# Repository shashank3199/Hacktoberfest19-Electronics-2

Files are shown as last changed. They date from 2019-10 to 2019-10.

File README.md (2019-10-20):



# Electronics-2

## Introduction
This repository contains the board design for Manual Bot Controller Shield for Arduino Mega 2560.

## Layout

### Board File -

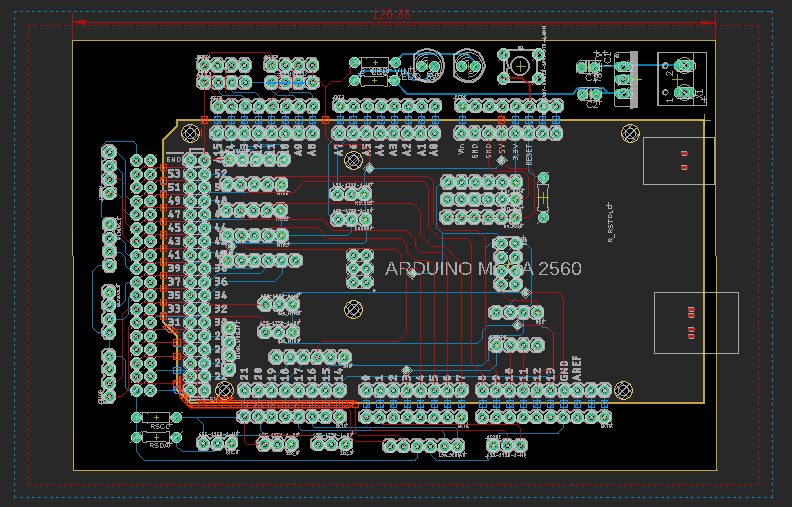
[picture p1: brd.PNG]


### Schematic File -

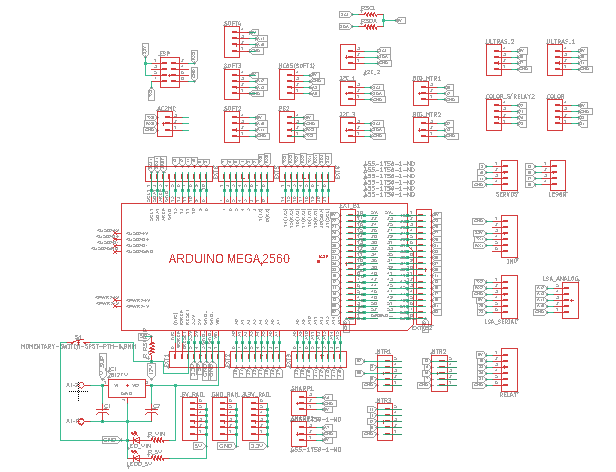
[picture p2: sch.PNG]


## Files in the Repository
The files in the repository are :

#### ManualBot_Shield.brd
This is the Board file and contains the Blueprint of the Shield Layout (Prototype).

#### ManualBot_Shield.sch
This is the Schematic file and contains the actual circuitary behind the Shield.

#### README.md
The Description file containing details about the repository. The file that you looking at right now.




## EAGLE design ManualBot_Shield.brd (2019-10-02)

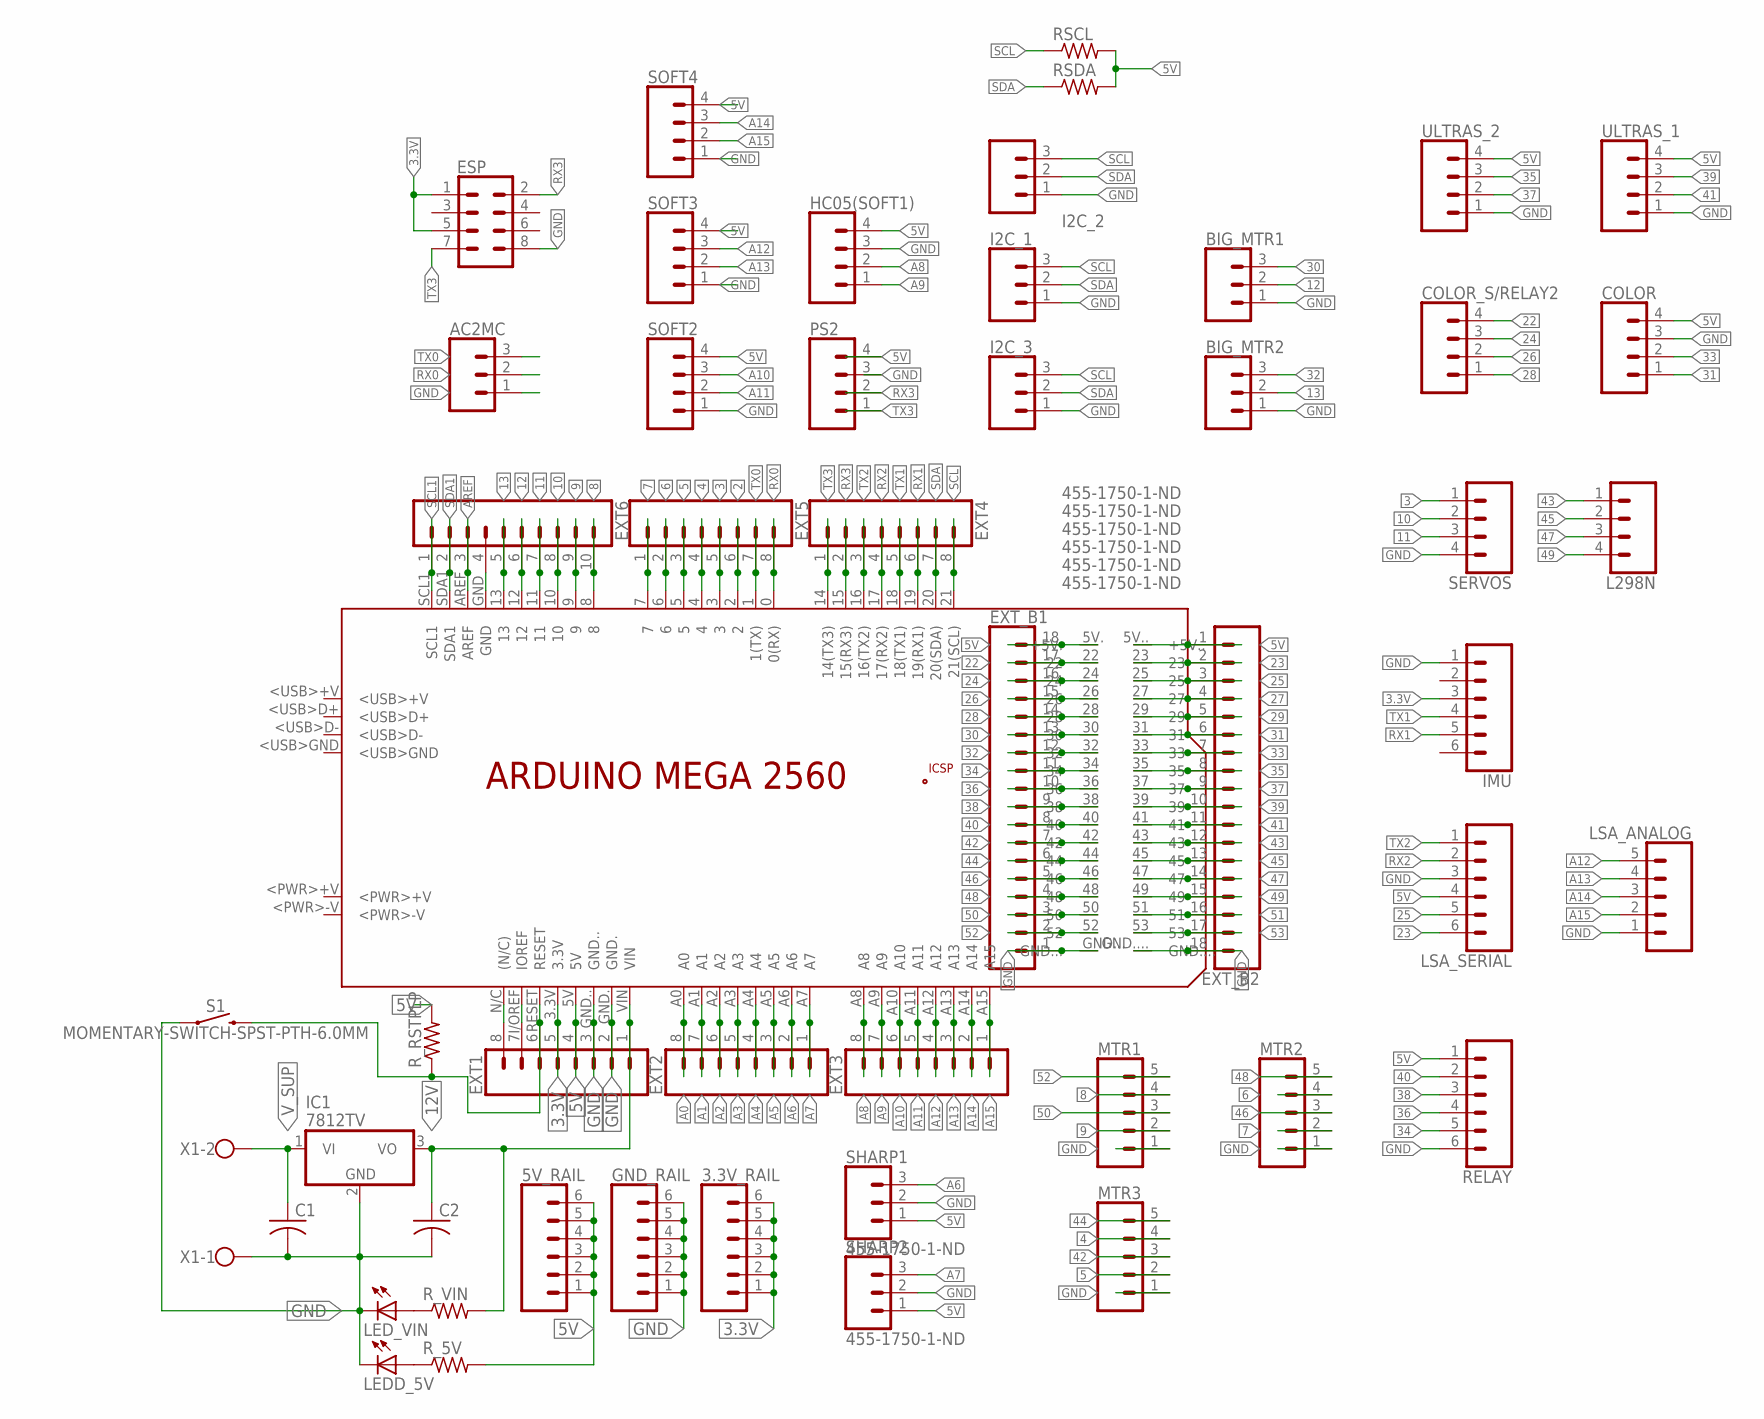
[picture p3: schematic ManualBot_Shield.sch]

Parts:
3.3V_RAIL, 5V_RAIL: CONN_06SILK_FEMALE_PTH; 1X06
AC2MC: 455-1750-1-ND; 1X03
BIG_MTR1, BIG_MTR2: 455-1750-1-ND; 1X03
C1, C2: C-US025-024X044; C025-024X044
COLOR: CONN_04; 1X04
COLOR_S/RELAY2: CONN_04; 1X04
ESP: CONN_04X2; 2X4
EXT1, EXT2, EXT3, EXT4, EXT5: CONN_08"; 1X08
EXT6: CONN_10"; 1X10
EXT_B1, EXT_B2: CONN_18; 1X18_NO_SILK
GND_RAIL: CONN_06SILK_FEMALE_PTH; 1X06
HC05(SOFT1): CONN_04; 1X04
I2C_1, I2C_2, I2C_3: 455-1750-1-ND; 1X03
IC1: 7812TV; TO220V
IMU: CONN_06SILK_FEMALE_PTH; 1X06
L298N: CONN_04; 1X04
LEDD_5V: LED5MM
LED_VIN: LED5MM
LSA_ANALOG: CONN_05; 1X05
LSA_SERIAL: CONN_06SILK_FEMALE_PTH; 1X06
MTR1, MTR2, MTR3: CONN_05; 1X05
PCB1: ARDUINO_MEGA2560
PS2: CONN_04; 1X04
RELAY: CONN_06SILK_FEMALE_PTH; 1X06
RSCL: R-US_0204/7; 0204/7
RSDA: R-US_0204/7; 0204/7
R_5V: R-US_0204/7; 0204/7
R_RSTPLP: R-US_0204/7; 0204/7
R_VIN: R-US_0204/7; 0204/7
S1: MOMENTARY-SWITCH-SPST-PTH-6.0MM; TACTILE_SWITCH_PTH_6.0MM
SERVOS: CONN_04; 1X04
SHARP1, SHARP2: 455-1750-1-ND; 1X03
SOFT2, SOFT3, SOFT4: CONN_04; 1X04
ULTRAS_1, ULTRAS_2: CONN_04; 1X04
X1: W237-102

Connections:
2: EXT5.6, PCB1.2
3: EXT5.5, PCB1.3, SERVOS.1
3.3V: 3.3V_RAIL.1, 3.3V_RAIL.2, 3.3V_RAIL.3, 3.3V_RAIL.4, 3.3V_RAIL.5, 3.3V_RAIL.6, ESP.1, ESP.5, EXT1.5, IMU.3, PCB1.3.3V
4: EXT5.4, MTR3.4, PCB1.4
5: EXT5.3, MTR3.2, PCB1.5
5V: 5V_RAIL.1, 5V_RAIL.2, 5V_RAIL.3, 5V_RAIL.4, 5V_RAIL.5, 5V_RAIL.6, COLOR.4, EXT1.4, EXT_B1.18, EXT_B2.1, HC05(SOFT1).4, LSA_SERIAL.4, PCB1.5V, PCB1.5V. (+5V.), PCB1.5V.. (+5V..), PS2.4, RELAY.1, RSCL.2, RSDA.2, R_5V.2, R_RSTPLP.2, SHARP1.1, SHARP2.1, SOFT2.4, SOFT3.4, SOFT4.4, ULTRAS_1.4, ULTRAS_2.4
6: EXT5.2, MTR2.4, PCB1.6
7: EXT5.1, MTR2.2, PCB1.7
8: EXT6.10, MTR1.4, PCB1.8
9: EXT6.9, MTR1.2, PCB1.9
10: EXT6.8, PCB1.10, SERVOS.2
11: EXT6.7, PCB1.11, SERVOS.3
12: BIG_MTR1.2, EXT6.6, PCB1.12
12V: C2.1, EXT1.1, IC1.3 (VO), PCB1.VIN, R_VIN.2
13: BIG_MTR2.2, EXT6.5, PCB1.13
22: COLOR_S/RELAY2.4, EXT_B1.17, PCB1.22
23: EXT_B2.2, LSA_SERIAL.6, PCB1.23
24: COLOR_S/RELAY2.3, EXT_B1.16, PCB1.24
25: EXT_B2.3, LSA_SERIAL.5, PCB1.25
26: COLOR_S/RELAY2.2, EXT_B1.15, PCB1.26
27: EXT_B2.4, PCB1.27
28: COLOR_S/RELAY2.1, EXT_B1.14, PCB1.28
29: EXT_B2.5, PCB1.29
30: BIG_MTR1.3, EXT_B1.13, PCB1.30
31: COLOR.1, EXT_B2.6, PCB1.31
32: BIG_MTR2.3, EXT_B1.12, PCB1.32
33: COLOR.2, EXT_B2.7, PCB1.33
34: EXT_B1.11, PCB1.34, RELAY.5
35: EXT_B2.8, PCB1.35, ULTRAS_2.3
36: EXT_B1.10, PCB1.36, RELAY.4
37: EXT_B2.9, PCB1.37, ULTRAS_2.2
38: EXT_B1.9, PCB1.38, RELAY.3
39: EXT_B2.10, PCB1.39, ULTRAS_1.3
40: EXT_B1.8, PCB1.40, RELAY.2
41: EXT_B2.11, PCB1.41, ULTRAS_1.2
42: EXT_B1.7, MTR3.3, PCB1.42
43: EXT_B2.12, L298N.1, PCB1.43
44: EXT_B1.6, MTR3.5, PCB1.44
45: EXT_B2.13, L298N.2, PCB1.45
46: EXT_B1.5, MTR2.3, PCB1.46
47: EXT_B2.14, L298N.3, PCB1.47
48: EXT_B1.4, MTR2.5, PCB1.48
49: EXT_B2.15, L298N.4, PCB1.49
50: EXT_B1.3, MTR1.3, PCB1.50
51: EXT_B2.16, PCB1.51
52: EXT_B1.2, MTR1.5, PCB1.52
53: EXT_B2.17, PCB1.53
A0: EXT2.8, PCB1.A0
A1: EXT2.7, PCB1.A1
A2: EXT2.6, PCB1.A2
A3: EXT2.5, PCB1.A3
A4: EXT2.4, PCB1.A4
A5: EXT2.3, PCB1.A5
A6: EXT2.2, PCB1.A6, SHARP1.3
A7: EXT2.1, PCB1.A7, SHARP2.3
A8: EXT3.8, HC05(SOFT1).2, PCB1.A8
A9: EXT3.7, HC05(SOFT1).1, PCB1.A9
A10: EXT3.6, PCB1.A10, SOFT2.3
A11: EXT3.5, PCB1.A11, SOFT2.2
A12: EXT3.4, LSA_ANALOG.5, PCB1.A12, SOFT3.3
A13: EXT3.3, LSA_ANALOG.4, PCB1.A13, SOFT3.2
A14: EXT3.2, LSA_ANALOG.3, PCB1.A14, SOFT4.3
A15: EXT3.1, LSA_ANALOG.2, PCB1.A15, SOFT4.2
AREF: EXT6.3, PCB1.AREF
GND: AC2MC.1, BIG_MTR1.1, BIG_MTR2.1, C1.2, C2.2, COLOR.3, ESP.8, EXT1.2, EXT1.3, EXT6.4, EXT_B1.1, EXT_B2.18, GND_RAIL.1, GND_RAIL.2, GND_RAIL.3, GND_RAIL.4, GND_RAIL.5, GND_RAIL.6, HC05(SOFT1).3, I2C_1.1, I2C_2.1, I2C_3.1, IC1.2 (GND), IMU.1, LEDD_5V.K (C), LED_VIN.K (C), LSA_ANALOG.1, LSA_SERIAL.3, MTR1.1, MTR2.1, MTR3.1, PCB1.GND, PCB1.GND., PCB1.GND.., PCB1.GND..., PCB1.GND...., PS2.3, RELAY.6, S1.1, SERVOS.4, SHARP1.2, SHARP2.2, SOFT2.1, SOFT3.1, SOFT4.1, ULTRAS_1.1, ULTRAS_2.1, X1.1
unnamed: LED_VIN.A, R_VIN.1
unnamed: LEDD_5V.A, R_5V.1
unnamed: EXT1.6, PCB1.RESET, R_RSTPLP.1, S1.3 (2)
unnamed: EXT1.7, PCB1.I/OREF (IOREF)
unnamed: EXT1.8, PCB1.N/C ((N/C))
RX0: AC2MC.2, EXT5.8, PCB1.0 (0(RX))
RX1: EXT4.6, IMU.5, PCB1.19 (19(RX1))
RX2: EXT4.4, LSA_SERIAL.2, PCB1.17 (17(RX2))
RX3: ESP.2, EXT4.2, PCB1.15 (15(RX3)), PS2.2
SCL: EXT4.8, I2C_1.3, I2C_2.3, I2C_3.3, PCB1.21 (21(SCL)), RSCL.1
SCL1: EXT6.1, PCB1.SCL1
SDA: EXT4.7, I2C_1.2, I2C_2.2, I2C_3.2, PCB1.20 (20(SDA)), RSDA.1
SDA1: EXT6.2, PCB1.SDA1
TX0: AC2MC.3, EXT5.7, PCB1.1 (1(TX))
TX1: EXT4.5, IMU.4, PCB1.18 (18(TX1))
TX2: EXT4.3, LSA_SERIAL.1, PCB1.16 (16(TX2))
TX3: ESP.7, EXT4.1, PCB1.14 (14(TX3)), PS2.1
V_SUP: C1.1, IC1.1 (VI), X1.2

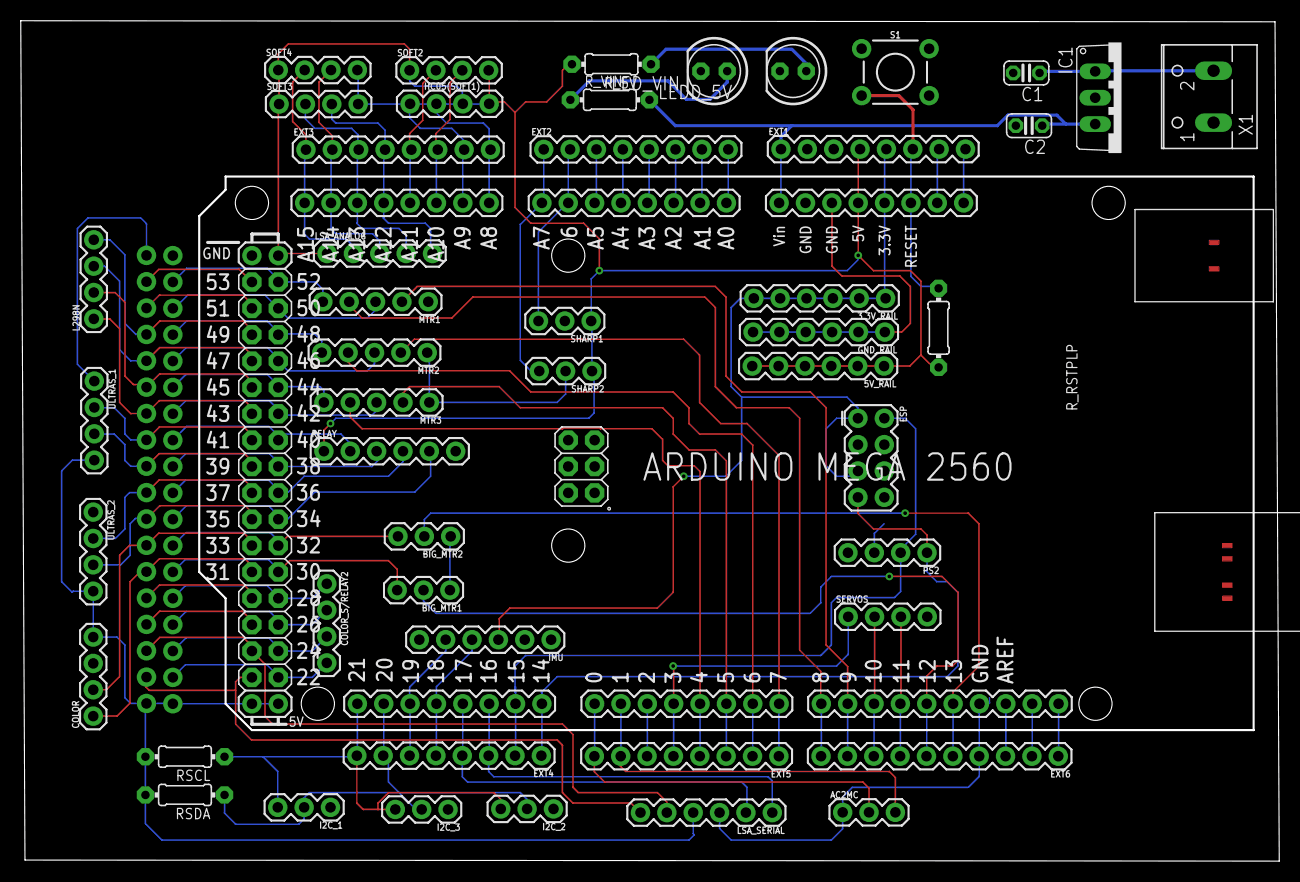
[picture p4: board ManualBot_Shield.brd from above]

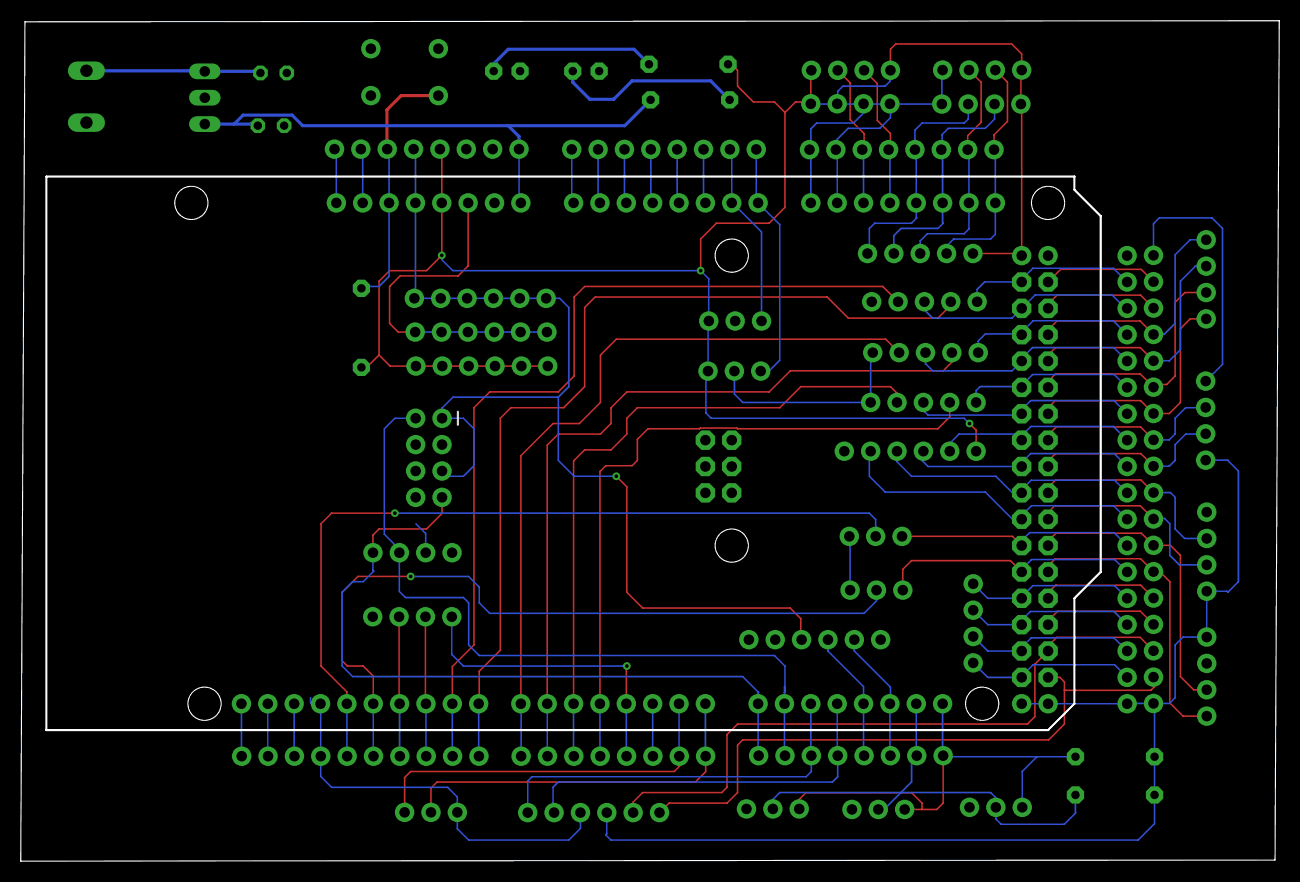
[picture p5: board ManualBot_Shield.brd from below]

Board: 2 copper layers, 121.3 x 81.0 mm, 51 parts (2 on the bottom side), 83 nets.

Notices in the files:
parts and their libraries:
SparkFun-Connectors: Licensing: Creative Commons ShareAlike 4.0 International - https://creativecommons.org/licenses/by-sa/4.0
